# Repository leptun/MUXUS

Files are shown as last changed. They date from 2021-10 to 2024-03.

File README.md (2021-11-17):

# MUXUS
This repository contains the MUXUS project, a USB 2.0 switch with 4 inputs (3xB + 1C_PD) and 4 outputs (3xA + STM32)





The project is split into multiple logical parts, all interconected on a PCB.
1. Upstream USB ports
2. USB mux
3. USB hub
4. Downstream USB ports
5. STM32 microcontroller
6. USB PD sink
7. STM32 programming
8. 3.3V rail Buck converter

## 1. Upstream USB ports
There are 4 upstream capable USB ports (UFP1-UFP4): 3x USB-B and 1xUSB-C

The USB-B ports (UFP2-4) are protected by `USBLC6-2SC6` ICs (VBUS, D+/-).

The USB-C port (UFP1) is protected by a `USBLC6-4SC6` IC (VBUS, D+/-, CC1/2).

## 2. USB mux
All Upstream facing ports (UFP) are connected to the USB mux IC (`TS3USBCA420RSVR`).
The mux output is connected to an internal usb bus called IFP (inner facing port).
Even though this IC is designed to multiplex SBU pins on USB-C ports, its bandwidth is high enough for USB 2.0 signals.
This IC is connected to the MCU via a 400KHz I2C bus. All control is done via I2C.

## 3. USB hub
The IFP bus is split into multiple downstream ports (DFP1-DFP4) using a USB 2.0 HS hub (`USB2504A-JT`).
The hub has an I2C interface as well and it is connected to the MCU via the same 400KHz I2C bus.
Most of the control is done via the I2C bus, but there are also a few extra pins required:
- HUB_RESET. It is an active low signal with an external pull-up resistor. It is needed because the I2C bus gets disabled by the hub when the Attach command is executed by the hub.
- IFP_VBUS. The MCU emulates the VBUS connection of the upstream ports since the MUX IC doesn't do that on its own.

Each DFP has a pair of status LEDs (green and amber):
- The green LED indicates if the device is connected and powered. It turns off when the device is suspended or when it is disconnected.
- The amber LED indicates a fault in the port. This seems to only happen when the VBUS is shorted to GND.

## 4. Downstream USB ports
There are 4 downstream capable ports (DFP1-4), however only 3 have connectors (DFP2-4).

DFP1 is connected directly to the mcu and, as a result, no power circuitry is required for this one.

DFP2-4 are usb-A ports. Each port is protected by `USBLC6-2SC6` ICs (VBUS, D+/-) and VBUS is switched using `AP2151W` ICs.

## 5. STM32 microcontroller
The MCU is a `STM32G441KBU6`.
There are a few reasons why this mcu was chosen, but the main restriction that made me choose this was the IC shortage.

The requirements for the mcu were as follows:
- Enough pins for controlling the board. A QFN32 IC was barely enough for this task. A 48 pin IC would have been much easier to use.
- 4 ADC inputs
- An I2C bus
- USB C PD capabilities
- Some kind of debug interface

Even though these requirements could have been fulfilled by much simpler MCUs, I chose this one as I wanted to learn how to use this MCU family.

## 6. USB PD sink
I wanted this hub to be fully featured, so I made sure that all downstream ports are capable of delivering the full USB 2.0 power specification.
As a result, 1.5A + whatever else consumes power on the board is required. The only method I could achieve this is by either using an external 5V power supply, or by using a USBC-PD capable charger. I chose the latter.
With USBC-PD, the board can communicate with the charger directly and request up to 3A at 5V. I configured it to only request 2A.
The UCPD stack provided by ST is surprisingly heavy, eating up ~70KB of flash. Luckily, it leaves enough flash for the rest of the code.

# 7. STM32 programming
The MCU can be programmed in multiple ways:
- The STDC14 connector is the main method I used. It has a SWD interface, SWO trace support and a UART interface to the programmer, making development extremely easy, especially for the STM32CubeMonitor-UCPD tool. Even though the connector is a bit more expensive than I'd like, it is a single connector debug interface that has everything I'd ever need and it is compatible with the STLINK-V3 programmmer. The connector Part number is `FTSH-107-01-L-DV-K-A`
- A pair of 2.54mm pin headers. The same signals are exposed just like in the STDC14 connector, but in a less pleasant pinout.
- USB DFU firmware upload. If the CYCLE/BOOT0 button is held pressed while the reset button is released, the board enters the system memory boot option, through which code can be uploaded. Due to the way the hub is controlled, resetting the mcu will keep the last mux connection active, so code can be flashed through the mux and hub. There is a small design issue however (more on that in the Known issues section).

# 8. 3.3V rail Buck converter
This buck converter (`AOZ1212AI`) powers all the 3.3V ICs.
It is waaaaay overkill for this project, but I already had the ICs and wanted to implement them.
A small LDO would have been much better suited and it might even have been more stable.

# Known issues
- rev1
  - The ICs are painful to solder. I shouldn't have chosen QFN packages. Lesson learned.
  - The clock circuitry for the hub is wrong. 32pF capacitors should have been used and there should also be a 1M resistor between the crystal leads.
  - The USB signal routing is *horrible*. I'm surprised it works at all. I should improve that aspect if I ever make another revision (:doubt:).
  - There is a pinout conflict between the UCPD dead battery signals and the system memory DFU bootloader. When entering the bootloader, the DBCC1 gets assigned as USART1_TX, disabling the dead battery signal. As a result, power gets cut. This issue can be avoided if the usb C cable is connected with one of the ends reversed, so it works only 50% of the time. There are two solutions for a future revision of the board: I could use a protection IC with integrated DB signals such as the one used in X-NUCLEO-USBPDM1, or I could just use an MCU which doesn't have this pinout conflict (such as STM32G0B1KET6N or similar).
  - The component placement could be better and the board could be smaller.

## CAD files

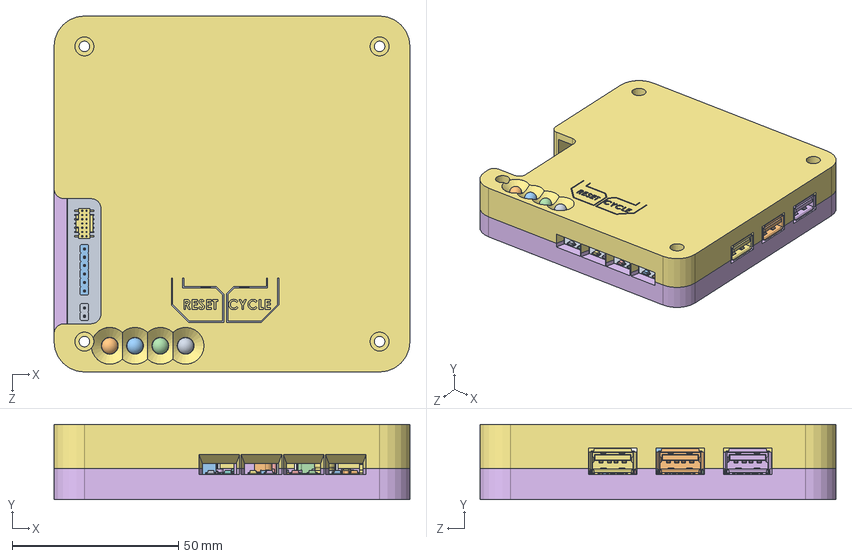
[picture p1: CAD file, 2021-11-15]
Plastic case/MUXUS-full.SLDASM
107.2 x 22.6 x 107.2 mm
Pcb_95df^Board_Geoms_95df_MUXUS
Chamfer^L1_ASSEMBLY_000061512f53_Top_95df_Step_Models_95df_MUXUS
FilletPin1^L1_ASSEMBLY_000061512f53_Top_95df_Step_Models_95df_MUXUS
FilletPin2^L1_ASSEMBLY_000061512f53_Top_95df_Step_Models_95df_MUXUS
FRAME-RSV0016A^FRAME-RSV0016A016_U6_RSV0016A_ASM_0000615132be_Top_95df_Step_Models_95df_MUXUS
FRAME-RSV0016A001^FRAME-RSV0016A016_U6_RSV0016A_ASM_0000615132be_Top_95df_Step_Models_95df_MUXUS
FRAME-RSV0016A002^FRAME-RSV0016A016_U6_RSV0016A_ASM_0000615132be_Top_95df_Step_Models_95df_MUXUS
FRAME-RSV0016A003^FRAME-RSV0016A016_U6_RSV0016A_ASM_0000615132be_Top_95df_Step_Models_95df_MUXUS
FRAME-RSV0016A004^FRAME-RSV0016A016_U6_RSV0016A_ASM_0000615132be_Top_95df_Step_Models_95df_MUXUS
FRAME-RSV0016A005^FRAME-RSV0016A016_U6_RSV0016A_ASM_0000615132be_Top_95df_Step_Models_95df_MUXUS
FRAME-RSV0016A006^FRAME-RSV0016A016_U6_RSV0016A_ASM_0000615132be_Top_95df_Step_Models_95df_MUXUS
FRAME-RSV0016A007^FRAME-RSV0016A016_U6_RSV0016A_ASM_0000615132be_Top_95df_Step_Models_95df_MUXUS
FRAME-RSV0016A008^FRAME-RSV0016A016_U6_RSV0016A_ASM_0000615132be_Top_95df_Step_Models_95df_MUXUS
FRAME-RSV0016A009^FRAME-RSV0016A016_U6_RSV0016A_ASM_0000615132be_Top_95df_Step_Models_95df_MUXUS
FRAME-RSV0016A010^FRAME-RSV0016A016_U6_RSV0016A_ASM_0000615132be_Top_95df_Step_Models_95df_MUXUS
FRAME-RSV0016A011^FRAME-RSV0016A016_U6_RSV0016A_ASM_0000615132be_Top_95df_Step_Models_95df_MUXUS
FRAME-RSV0016A012^FRAME-RSV0016A016_U6_RSV0016A_ASM_0000615132be_Top_95df_Step_Models_95df_MUXUS
FRAME-RSV0016A013^FRAME-RSV0016A016_U6_RSV0016A_ASM_0000615132be_Top_95df_Step_Models_95df_MUXUS
FRAME-RSV0016A014^FRAME-RSV0016A016_U6_RSV0016A_ASM_0000615132be_Top_95df_Step_Models_95df_MUXUS
FRAME-RSV0016A015^FRAME-RSV0016A016_U6_RSV0016A_ASM_0000615132be_Top_95df_Step_Models_95df_MUXUS
BODY-SON1^U6_RSV0016A_ASM_0000615132be_Top_95df_Step_Models_95df_MUXUS
Body^U7_ASSEMBLY_00006158deb1_Top_95df_Step_Models_95df_MUXUS
ThermalPin^U7_ASSEMBLY_00006158deb1_Top_95df_Step_Models_95df_MUXUS
PinsArrayLR^U7_ASSEMBLY_00006158deb1_Top_95df_Step_Models_95df_MUXUS
PinsArrayTB^U7_ASSEMBLY_00006158deb1_Top_95df_Step_Models_95df_MUXUS
C1_C_0805_2012Metric_000061512a82^Top_95df_Step_Models_95df_MUXUS
C2_C_0805_2012Metric_000061512a93^Top_95df_Step_Models_95df_MUXUS
C3_C_0805_2012Metric_000061512aa4^Top_95df_Step_Models_95df_MUXUS
C7_C_1206_3216Metric_000061512ab5^Top_95df_Step_Models_95df_MUXUS
C5_C_1206_3216Metric_000061512ac6^Top_95df_Step_Models_95df_MUXUS
C4_C_1206_3216Metric_000061512ad7^Top_95df_Step_Models_95df_MUXUS
C6_C_1206_3216Metric_000061512ae8^Top_95df_Step_Models_95df_MUXUS
C9_C_0805_2012Metric_000061512b0a^Top_95df_Step_Models_95df_MUXUS
C10_C_0805_2012Metric_000061512b1b^Top_95df_Step_Models_95df_MUXUS
C11_C_0805_2012Metric_000061512b2c^Top_95df_Step_Models_95df_MUXUS
C12_C_0805_2012Metric_000061512b3d^Top_95df_Step_Models_95df_MUXUS
C13_C_0805_2012Metric_000061512b4e^Top_95df_Step_Models_95df_MUXUS
C14_C_0805_2012Metric_000061512b5f^Top_95df_Step_Models_95df_MUXUS
C15_C_Radial_D63mm_H110mm_P250mm_000061512b69^Top_95df_Step_Models_95df_MUXUS
C17_C_0805_2012Metric_000061512b8b^Top_95df_Step_Models_95df_MUXUS
C18_C_0805_2012Metric_000061512b9c^Top_95df_Step_Models_95df_MUXUS
C19_C_0805_2012Metric_000061512bad^Top_95df_Step_Models_95df_MUXUS
C20_C_0805_2012Metric_000061512bbe^Top_95df_Step_Models_95df_MUXUS
C23_C_0805_2012Metric_000061512bf1^Top_95df_Step_Models_95df_MUXUS
C24_C_0805_2012Metric_000061512c02^Top_95df_Step_Models_95df_MUXUS
C26_C_0805_2012Metric_000061512c24^Top_95df_Step_Models_95df_MUXUS
C27_C_0805_2012Metric_000061512c35^Top_95df_Step_Models_95df_MUXUS
C29_C_0805_2012Metric_000061512c50^Top_95df_Step_Models_95df_MUXUS
C31_C_0805_2012Metric_000061512c72^Top_95df_Step_Models_95df_MUXUS
C32_C_0805_2012Metric_000061512c83^Top_95df_Step_Models_95df_MUXUS
C33_C_0805_2012Metric_000061512c94^Top_95df_Step_Models_95df_MUXUS
C34_C_0805_2012Metric_000061512ca5^Top_95df_Step_Models_95df_MUXUS
C35_C_0805_2012Metric_000061512cb6^Top_95df_Step_Models_95df_MUXUS
C36_C_0805_2012Metric_000061512cc7^Top_95df_Step_Models_95df_MUXUS
C38_C_0805_2012Metric_000061512ce2^Top_95df_Step_Models_95df_MUXUS
C39_C_1210_3225Metric_000061512cf3^Top_95df_Step_Models_95df_MUXUS
C40_C_0805_2012Metric_000061512d04^Top_95df_Step_Models_95df_MUXUS
D1_LED_1206_3216Metric_000061512d17^Top_95df_Step_Models_95df_MUXUS
D2_LED_1206_3216Metric_000061512d2a^Top_95df_Step_Models_95df_MUXUS
D3_LED_1206_3216Metric_000061512d3d^Top_95df_Step_Models_95df_MUXUS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

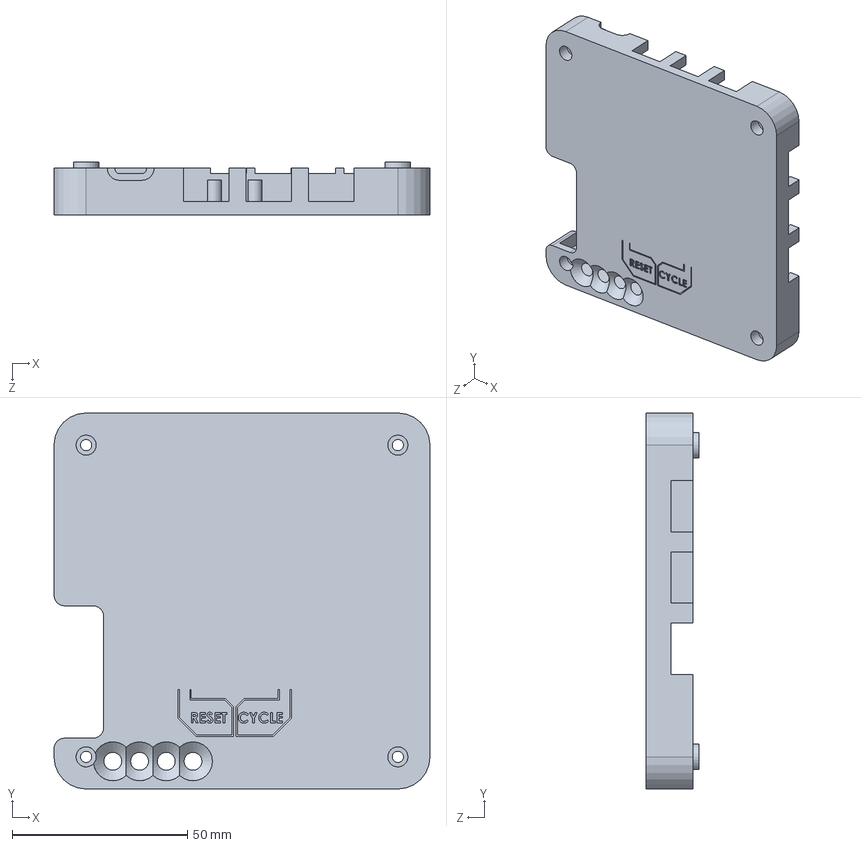
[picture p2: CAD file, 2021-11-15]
Plastic case/MUXUS-top.SLDPRT
107.2 x 107.2 x 15.0 mm

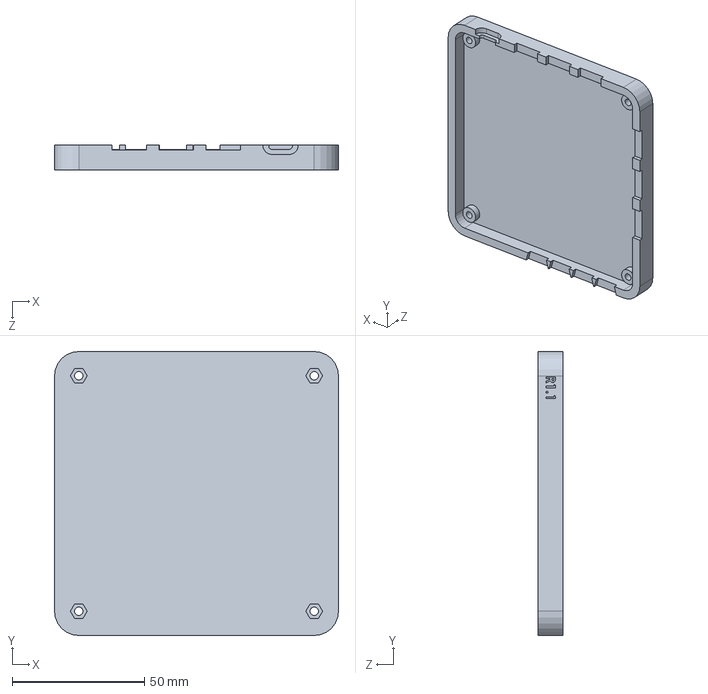
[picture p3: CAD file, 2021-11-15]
Plastic case/MUXUS-base.SLDPRT
107.2 x 107.2 x 9.28 mm

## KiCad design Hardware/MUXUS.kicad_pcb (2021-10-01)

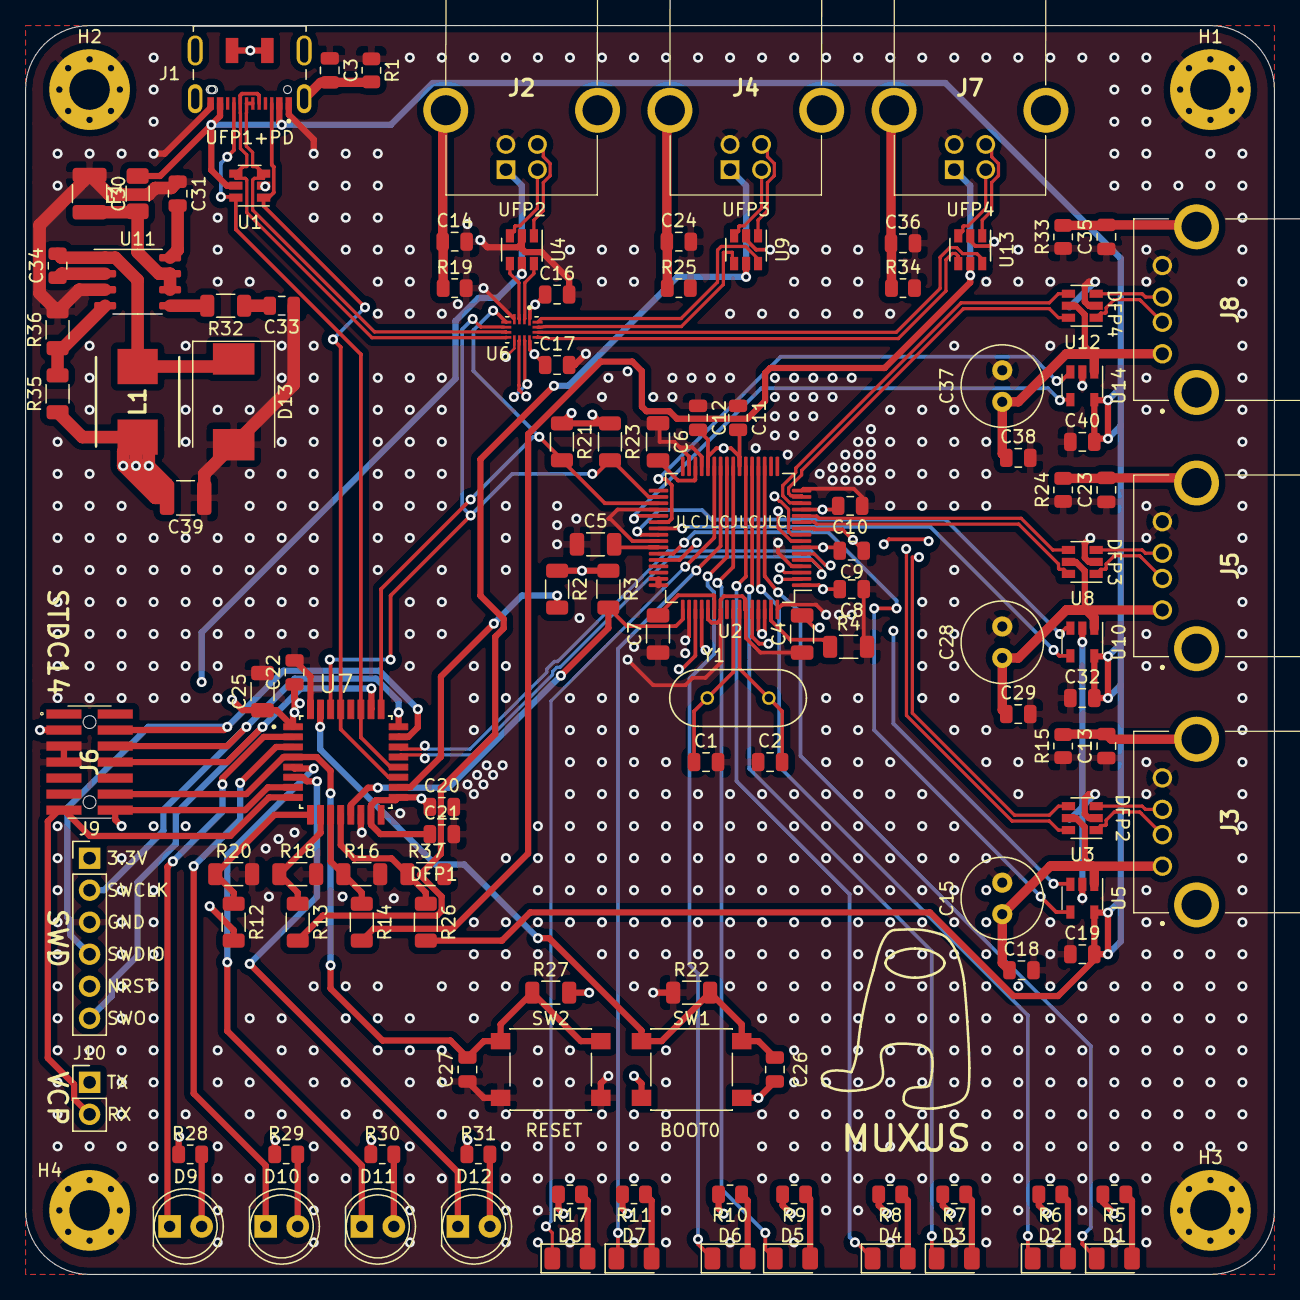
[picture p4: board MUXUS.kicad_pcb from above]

Board: 4 copper layers, 99.1 x 99.1 mm, 124 parts (0 on the bottom side), 107 nets.

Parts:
C1, C2: 15pF; C_0805_2012Metric
C3, C8, C9, C10, C11, C12, C13, C14, C17, C18, C19, C20, C21, C22, C23, C24, C26, C27, C29, C32, C34, C35, C36, C38, C40: 100nF; C_0805_2012Metric
C4, C5, C6, C7, C25: 4.7uF; C_1206_3216Metric
C15, C28, C37: 120uF; C_Radial_D6.3mm_H11.0mm_P2.50mm
C16, C31: 1uF; C_0805_2012Metric
C30, C39: 22uF; C_1210_3225Metric
C33: 100pF; C_0805_2012Metric
D1, D3, D5, D7: AMBER; LED_1206_3216Metric
D2, D4, D6, D8: GREEN; LED_1206_3216Metric
D9, D10, D11, D12: LED; LED_D5.0mm
D13: B540C-13-F; D_SMC
F1: 500mA; Fuse_1206_3216Metric
H1, H2, H3, H4: MountingHole_Pad; MountingHole_3.2mm_M3_Pad_Via
J1: USB_C_Receptacle_USB2.0; DX07S016JA1R1500
J2, J4, J7: USB_B; 67068-9000
J3, J5, J8: USB_A; 67643-0910
J6: STDC14; FTSH-107-01-L-DV-K-A
J9: SWD; PinHeader_1x06_P2.54mm_Vertical
J10: VCP; PinHeader_1x02_P2.54mm_Vertical
L1: SRP6530A-6R8M
R1, R15, R19, R24, R25, R33, R34: 330R; R_0805_2012Metric
R2, R16, R18, R20, R21, R23, R37: 1K; R_1206_3216Metric
R3, R12, R13, R14, R22, R26, R27, R36: 10K; R_1206_3216Metric
R4: 12K; R_1206_3216Metric
R5, R6, R7, R8, R9, R10, R11, R17, R28, R29, R30, R31: 100R; R_0805_2012Metric
R32: 15K; R_1206_3216Metric
R35: 31.6K; R_1206_3216Metric
SW1: USER; SW_Push_1P1T_NO_6x6mm_H9.5mm
SW2: RESET; SW_Push_1P1T_NO_6x6mm_H9.5mm
SYM1: AMOGUS; SUS
U1: USBLC6-4SC6; SOT-23-6
U2: USB2504A-JT; LQFP-64_10x10mm_P0.5mm
U3, U4, U8, U9, U12, U13: USBLC6-2SC6; SOT-23-6
U5, U10, U14: AP2151W; SOT-23-5
U6: TS3USBCA420RSVR
U7: STM32G431K8T6
U11: AOZ1212AI; SO-8_3.9x4.9mm_P1.27mm
Y1: ATS240C

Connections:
+3V3: C8.2, C9.2, C10.2, C11.2, C12.2, C16.1, C17.1, C20.1, C21.1, C22.1, C25.1, C26.1, C39.2, J6.3, J9.1, L1.2, R2.1, R3.1, R5.2, R6.2, R7.2, R8.2, R9.2, R10.2, R11.2, R17.2, R21.1, R23.1, R27.2, R28.1, R29.1, R30.1, R31.1, R35.1, SW1.2, U2.1, U2.7, U2.13, U2.23, U2.28, U2.51, U2.61, U2.62, U6.1, U6.12, U7.1, U7.15, U7.17
BOOT0: C26.2, R22.2, SW1.1, U7.31
CC1: J1.A5, U1.1, U7.19, U7.29
CC2: J1.B5, U1.6, U7.20, U7.27
DFP1_D+: U2.6, U7.22
DFP1_D-: U2.5, U7.21
DFP2_CONN_D+: J3.3, U3.3
DFP2_CONN_D-: J3.2, U3.1
DFP2_D+: U2.8, U3.4
DFP2_D-: U2.9, U3.6
DFP2_EN: U2.43, U5.4
DFP2_OCSn: U2.44, U5.3
DFP3_CONN_D+: J5.3, U8.3
DFP3_CONN_D-: J5.2, U8.1
DFP3_D+: U2.12, U8.4
DFP3_D-: U2.11, U8.6
DFP3_EN: U2.39, U10.4
DFP3_OCSn: U2.40, U10.3
DFP4_CONN_D+: J8.3, U12.3
DFP4_CONN_D-: J8.2, U12.1
DFP4_D+: U2.14, U12.4
DFP4_D-: U2.15, U12.6
DFP4_EN: U2.37, U14.4
DFP4_OCSn: U2.38, U14.3
GND: C1.2, C2.1, C3.1, C4.1, C5.1, C6.1, C7.1, C8.1, C9.1, C10.1, C11.1, C12.1, C13.1, C14.2, C15.2, C16.2, C17.2, C18.2, C19.1, C20.2, C21.2, C22.2, C23.1, C24.2, C25.2, C27.1, C28.2, C29.2, C30.1, C31.1, C32.1, C33.1, C35.1, C36.2, C37.2, C38.2, C39.1, C40.1, D13.2, H1.1, H2.1, H3.1, H4.1, J1.A1, J1.A12, J1.B1, J1.B12, J2.4, J3.4, J4.4, J5.4, J6.5, J6.7, J7.4, J8.4, J9.3, R1.1, R4.2, R15.1, R16.2, R18.2, R19.2, R20.2, R22.1, R24.1, R25.2, R33.1, R34.2, R36.2, R37.2, SW2.2, U1.2, U2.4, U2.10, U2.16, U2.29, U2.31, U2.36, U2.41, U2.47, U2.48, U2.50, U2.53, U2.55, U2.59, U2.64, U3.2, U4.2, U5.2, U6.4, U6.9, U7.14, U7.16, U7.32, U8.2, U9.2, U10.2, U11.3, U12.2, U13.2, U14.2
HUB_RESET: R3.2, U2.49, U7.13
I2C1_SCL: R21.2, U2.35, U6.5, U7.25
I2C1_SDA: R23.2, U2.34, U6.6, U7.30
IFP_D+: U2.2, U6.11
IFP_D-: U2.3, U6.10
IFP_VBUS: R2.2, U2.52, U7.18
LPUART1_RX: J6.13, J10.2, U7.8
LPUART1_TX: J6.14, J10.1, U7.7
NRST: C27.2, J6.12, J9.5, R27.1, SW2.1, U7.4
unnamed: C1.1, U2.57, Y1.1
unnamed: C2.2, U2.58, Y1.2
unnamed: C3.2, J1.S1, R1.2
unnamed: C4.2, U2.60
unnamed: C5.2, U2.42
unnamed: C6.2, U2.30
unnamed: C7.2, U2.54
unnamed: C13.2, J3.5, R15.2
unnamed: C14.1, J2.5, R19.1
unnamed: C15.1, C18.1, J3.1, U3.5, U5.1
unnamed: C23.2, J5.5, R24.2
unnamed: C24.1, J4.5, R25.1
unnamed: C28.1, C29.1, J5.1, U8.5, U10.1
unnamed: C30.2, F1.1, U11.6, U11.7
unnamed: C31.2, U11.8
unnamed: C33.2, R32.1
unnamed: C34.1, U11.2
unnamed: C34.2, D13.1, L1.1, U11.1
unnamed: C35.2, J8.5, R33.2
unnamed: C36.1, J7.5, R34.1
unnamed: C37.1, C38.1, J8.1, U12.5, U14.1
unnamed: D1.1, U2.19
unnamed: D1.2, R5.1
unnamed: D2.1, U2.20
unnamed: D2.2, R6.1
unnamed: D3.1, U2.21
unnamed: D3.2, R7.1
unnamed: D4.1, U2.22
unnamed: D4.2, R8.1
unnamed: D5.1, U2.24
unnamed: D5.2, R9.1
unnamed: D6.1, U2.25
unnamed: D6.2, R10.1
unnamed: D7.1, U2.26
unnamed: D7.2, R11.1
unnamed: D8.1, U2.27
unnamed: D8.2, R17.1
unnamed: D9.2, R28.2
unnamed: D10.2, R29.2
unnamed: D11.2, R30.2
unnamed: D12.2, R31.2
unnamed: R4.1, U2.63
unnamed: R12.1, R20.1, U7.9
unnamed: R13.1, R18.1, U7.10
unnamed: R14.1, R16.1, U7.11
unnamed: R26.1, R37.1, U7.12
unnamed: R32.2, U11.5
unnamed: R35.2, R36.1, U11.4
SWCLK: J6.6, J9.2, U7.24
SWDIO: J6.4, J9.4, U7.23
SWO: J6.8, J9.6, U7.26
UFP1_D+: J1.A6, J1.B6, U1.3, U6.7
UFP1_D-: J1.A7, J1.B7, U1.4, U6.8
UFP1_VBUS: C19.2, C32.2, C40.2, F1.2, J1.A4, J1.A9, J1.B4, J1.B9, R26.2, U1.5, U5.5, U10.5, U14.5
UFP2_CONN_D+: J2.3, U4.1
UFP2_CONN_D-: J2.2, U4.3
UFP2_D+: U4.6, U6.2
UFP2_D-: U4.4, U6.3
UFP2_VBUS: J2.1, R12.2, U4.5
UFP3_CONN_D+: J4.3, U9.1
UFP3_CONN_D-: J4.2, U9.3
UFP3_D+: U6.16, U9.6
UFP3_D-: U6.15, U9.4
UFP3_VBUS: J4.1, R13.2, U9.5
UFP4_CONN_D+: J7.3, U13.1
UFP4_CONN_D-: J7.2, U13.3
UFP4_D+: U6.14, U13.6
UFP4_D-: U6.13, U13.4
UFP4_VBUS: J7.1, R14.2, U13.5
UI_LED1: D9.1, U7.2
UI_LED2: D10.1, U7.3
UI_LED3: D11.1, U7.5
UI_LED4: D12.1, U7.6

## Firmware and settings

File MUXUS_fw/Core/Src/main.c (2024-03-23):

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
/* Includes ------------------------------------------------------------------*/
#include "main.h"
#include "cmsis_os.h"
#include "usbpd.h"
#include "usb_device.h"

/* USER CODE BEGIN Includes */

#include <bootapp.h>

/* USER CODE END Includes */

ADC_HandleTypeDef hadc1;
ADC_HandleTypeDef hadc2;
DMA_HandleTypeDef hdma_adc1;

I2C_HandleTypeDef hi2c1;
DMA_HandleTypeDef hdma_i2c1_rx;
DMA_HandleTypeDef hdma_i2c1_tx;

/* Definitions for defaultTask */
osThreadId_t defaultTaskHandle;
const osThreadAttr_t defaultTask_attributes = {
  .name = "defaultTask",
  .priority = (osPriority_t) osPriorityNormal,
  .stack_size = 128 * 4
};
/* Definitions for controlTask */
osThreadId_t controlTaskHandle;
const osThreadAttr_t controlTask_attributes = {
  .name = "controlTask",
  .priority = (osPriority_t) osPriorityNormal,
  .stack_size = 256 * 4
};
void SystemClock_Config(void);
static void MX_GPIO_Init(void);
static void MX_DMA_Init(void);
static void MX_ADC1_Init(void);
static void MX_ADC2_Init(void);
static void MX_I2C1_Init(void);
static void MX_LPUART1_UART_Init(void);
static void MX_UCPD1_Init(void);
void StartDefaultTask(void *argument);
extern void controlTask_main(void *argument);

/**
  * @brief  The application entry point.
  * @retval int
  */
int main(void)
{
  /* USER CODE BEGIN 1 */
  bootapp();
  /* USER CODE END 1 */

  /* MCU Configuration--------------------------------------------------------*/

  /* Reset of all peripherals, Initializes the Flash interface and the Systick. */
  HAL_Init();

  /* Configure the system clock */
  SystemClock_Config();

  /* Initialize all configured peripherals */
  MX_GPIO_Init();
  MX_DMA_Init();
  MX_ADC1_Init();
  MX_ADC2_Init();
  MX_I2C1_Init();
  MX_LPUART1_UART_Init();
  MX_UCPD1_Init();
  MX_USB_Device_Init();
  /* Init scheduler */
  osKernelInitialize();
  /* USBPD initialisation ---------------------------------*/
  MX_USBPD_Init();

  /* USER CODE BEGIN RTOS_MUTEX */
  /* add mutexes, ... */
  /* USER CODE END RTOS_MUTEX */

  /* USER CODE BEGIN RTOS_SEMAPHORES */
  /* add semaphores, ... */
  /* USER CODE END RTOS_SEMAPHORES */

  /* USER CODE BEGIN RTOS_TIMERS */
  /* start timers, add new ones, ... */
  /* USER CODE END RTOS_TIMERS */

  /* USER CODE BEGIN RTOS_QUEUES */
  /* add queues, ... */
  /* USER CODE END RTOS_QUEUES */

  /* Create the thread(s) */
  /* creation of defaultTask */
  defaultTaskHandle = osThreadNew(StartDefaultTask, NULL, &defaultTask_attributes);

  /* creation of controlTask */
  controlTaskHandle = osThreadNew(controlTask_main, NULL, &controlTask_attributes);

  /* USER CODE BEGIN RTOS_THREADS */
  /* add threads, ... */
  /* USER CODE END RTOS_THREADS */

  /* USER CODE BEGIN RTOS_EVENTS */
  /* add events, ... */
  /* USER CODE END RTOS_EVENTS */

  /* Start scheduler */
  osKernelStart();

  /* We should never get here as control is now taken by the scheduler */
  /* Infinite loop */
  /* USER CODE BEGIN WHILE */
  while (1)
  {
    /* USER CODE END WHILE */

    /* USER CODE BEGIN 3 */
  }
  /* USER CODE END 3 */
}

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
/* USER CODE BEGIN Header_StartDefaultTask */
/**
  * @brief  Function implementing the defaultTask thread.
  * @param  argument: Not used
  * @retval None
  */
/* USER CODE END Header_StartDefaultTask */
void StartDefaultTask(void *argument)
{
  /* USER CODE BEGIN 5 */
  /* Infinite loop */
	for (;;)
		osDelay(1);
  /* USER CODE END 5 */
}

/**
  * @brief  Period elapsed callback in non blocking mode
  * @note   This function is called  when TIM6 interrupt took place, inside
  * HAL_TIM_IRQHandler(). It makes a direct call to HAL_IncTick() to increment
  * a global variable "uwTick" used as application time base.
  * @param  htim : TIM handle
  * @retval None
  */
void HAL_TIM_PeriodElapsedCallback(TIM_HandleTypeDef *htim)
{
  if (htim->Instance == TIM6) {
    HAL_IncTick();
  }
  /* USER CODE BEGIN Callback 1 */
#ifdef _GUI_INTERFACE
  if (htim->Instance == TIM6) {
	  GUI_TimerCounter();
  }
#endif
  /* USER CODE END Callback 1 */
}

/**
  * @brief  This function is executed in case of error occurrence.
  * @retval None
  */
void Error_Handler(void)
{
  /* USER CODE BEGIN Error_Handler_Debug */
  /* User can add his own implementation to report the HAL error return state */
  __disable_irq();
  while (1)
  {
  }
  /* USER CODE END Error_Handler_Debug */
}

#ifdef  USE_FULL_ASSERT
/**
  * @brief  Reports the name of the source file and the source line number
  *         where the assert_param error has occurred.
  * @param  file: pointer to the source file name
  * @param  line: assert_param error line source number
  * @retval None
  */
void assert_failed(uint8_t *file, uint32_t line)
{
  /* USER CODE BEGIN 6 */
  /* User can add his own implementation to report the file name and line number,
     ex: printf("Wrong parameters value: file %s on line %d\r\n", file, line) */
  /* USER CODE END 6 */
}
#endif /* USE_FULL_ASSERT */

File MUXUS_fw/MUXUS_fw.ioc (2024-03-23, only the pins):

Mcu.UserName=STM32G441KBUx
PA0.GPIO_Label=VOLT3
PA0.Signal=ADC1_IN1
PA1.GPIO_Label=VOLT4
PA1.Signal=ADC1_IN2
PA10.Signal=UCPD1_DBCC2
PA11.Signal=USB_DM
PA12.Signal=USB_DP
PA13.Signal=SYS_JTMS-SWDIO
PA14.Signal=SYS_JTCK-SWCLK
PA15.Signal=I2C1_SCL
PA2.Signal=LPUART1_TX
PA3.Signal=LPUART1_RX
PA4.GPIO_Label=LED1
PA4.Signal=GPIO_Output
PA5.GPIO_Label=LED2
PA5.Signal=GPIO_Output
PA6.GPIO_Label=LED3
PA6.Signal=GPIO_Output
PA7.GPIO_Label=LED4
PA7.Signal=GPIO_Output
PA8.GPIO_Label=IFP_VBUS
PA8.Signal=GPIO_Output
PA9.Signal=UCPD1_DBCC1
PB0.GPIO_Label=HUB_RESET
PB0.Signal=GPIO_Output
PB3.Signal=SYS_JTDO-SWO
PB4.Signal=UCPD1_CC2
PB5.Signal=I2C1_SMBA
PB6.Signal=UCPD1_CC1
PB7.Signal=I2C1_SDA
PB8-BOOT0.GPIO_Label=BOOT0
PB8-BOOT0.Signal=GPIO_Input
PF0-OSC_IN.GPIO_Label=VOLT2
PF0-OSC_IN.Signal=ADC1_IN10
PF1-OSC_OUT.GPIO_Label=VOLT1
PF1-OSC_OUT.Signal=ADC2_IN10
PG10-NRST.GPIO_Label=NRST
PG10-NRST.Signal=GPIO_Input

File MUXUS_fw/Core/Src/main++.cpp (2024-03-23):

#include "pins.hpp"

#include "main.h"
#include "cmsis_os.h"
#include "bootapp.h"

#include <usb_device.h>

////std libs
//#include <stdio.h>
//#include <algorithm>

//libs
#include "USB2504A/USB2504A.hpp"
#include "TS3USBCA4/TS3USBCA4.hpp"

I2C_Wrapper i2c_bus(&hi2c1, "i2c_bus");
USB2504A hub(0x58, pins::HUB.RST, pins::HUB.IFP_VBUS, &i2c_bus);
TS3USBCA4 mux(0xBA, &i2c_bus);

constexpr TS3USBCA4::Channels upstreams[] {
	TS3USBCA4::Channels::DISABLED,
	TS3USBCA4::Channels::LnB,
	TS3USBCA4::Channels::MICGND,
	TS3USBCA4::Channels::LnA,
	TS3USBCA4::Channels::LnC,
};

uint8_t activeUpstream;
constexpr uint8_t defaultUpstream = 2;

constexpr USB2504A::Config hubConfig = {
	0x0424,
	0x2504,
	0x10A1,
	0xDB,
	0x18,
	0x02,
	0x00,
	0x00,
	0x00,
	0x64,
	0x00,
	0x64,
	0x32,
};

void switchToUpstream(uint8_t port) {
	activeUpstream = port;
	hub.reset();
	mux.setChannel(upstreams[activeUpstream], false);
	hub.writeConfig(hubConfig);
	hub.attach();

	for (uint8_t i = 0; i < (sizeof(pins::LEDs) / sizeof(pins::LEDs[0])); i++) {
		HAL_GPIO_WritePin(pins::LEDs[i].port, pins::LEDs[i].pin, ((i + 1) == activeUpstream) ? GPIO_PIN_RESET : GPIO_PIN_SET);
	}
}


uint32_t lastMSC_Pulse = 0;

void notify_check_for_ready(void) {
	lastMSC_Pulse = osKernelGetTickCount();
}

extern "C" void controlTask_main(void *argument) {
	osDelay(500);
	hub.init();
	mux.init();

	switchToUpstream(defaultUpstream);

	for(;;osDelay(1)) {
		if (HAL_GPIO_ReadPin(pins::USER.port, pins::USER.pin)) {
			uint32_t startTime = osKernelGetTickCount();
			osDelay(10); //debounce
			while (HAL_GPIO_ReadPin(pins::USER.port, pins::USER.pin))
				osDelay(1);
			uint32_t deltaTime = osKernelGetTickCount() - startTime;

			if (deltaTime < 5000) {
				activeUpstream++;
				if (activeUpstream >= (sizeof(upstreams) / sizeof(upstreams[0])))
					activeUpstream = 1;
				switchToUpstream(activeUpstream);
			}
			else {
				boot_app_magic = BOOT_APP_MAGIC;
				boot_app_flags = BOOT_APP_JMP_TO_SYSTEM_MEMORY;
				HAL_NVIC_SystemReset();
			}
		}

		if (osKernelGetTickCount() - lastMSC_Pulse > 10000) {
			MX_USB_Device_DeInit();
			osDelay(500);
			MX_USB_Device_Init();
			lastMSC_Pulse = osKernelGetTickCount();
		}
	}
}

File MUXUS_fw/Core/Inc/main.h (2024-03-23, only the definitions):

#define VOLT2_Pin GPIO_PIN_0
#define VOLT2_GPIO_Port GPIOF
#define VOLT1_Pin GPIO_PIN_1
#define VOLT1_GPIO_Port GPIOF
#define NRST_Pin GPIO_PIN_10
#define NRST_GPIO_Port GPIOG
#define VOLT3_Pin GPIO_PIN_0
#define VOLT3_GPIO_Port GPIOA
#define VOLT4_Pin GPIO_PIN_1
#define VOLT4_GPIO_Port GPIOA
#define LED1_Pin GPIO_PIN_4
#define LED1_GPIO_Port GPIOA
#define LED2_Pin GPIO_PIN_5
#define LED2_GPIO_Port GPIOA
#define LED3_Pin GPIO_PIN_6
#define LED3_GPIO_Port GPIOA
#define LED4_Pin GPIO_PIN_7
#define LED4_GPIO_Port GPIOA
#define HUB_RESET_Pin GPIO_PIN_0
#define HUB_RESET_GPIO_Port GPIOB
#define IFP_VBUS_Pin GPIO_PIN_8
#define IFP_VBUS_GPIO_Port GPIOA
#define BOOT0_Pin GPIO_PIN_8
#define BOOT0_GPIO_Port GPIOB

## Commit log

2021-09-12 Initial project
    [MUXUS.kicad_pcb, MUXUS.sch]
2021-09-12 First libs and project reorganization into HW and SW
    [MUXUS.kicad_pcb, MUXUS.sch]
2021-09-24 Checkpoint
    Supposed finalization of first prototype
    [MUXUS.sch]
2021-09-26 Prototype 1
2021-09-26 Mounting holes
    [MUXUS.sch]
2021-09-26 Basic board layout
    [MUXUS.kicad_pcb, MUXUS.sch]
2021-09-26 LED positioning
    [MUXUS.kicad_pcb]
2021-09-26 More footprint positioning
    [MUXUS.kicad_pcb]
2021-09-27 add older footprint from desktop
    todo: make combined libraries
2021-09-27 AMOGUS and USB C footprint update
    [MUXUS.kicad_pcb, MUXUS.sch]
2021-09-27 Component placement finished
    [MUXUS.kicad_pcb]
2021-09-27 Rounded board edges
    [MUXUS.kicad_pcb]
2021-09-27 Add trace widths
    [MUXUS.kicad_pcb]
2021-09-27 Basic routing
    [MUXUS.kicad_pcb]
2021-09-27 First PCB routing
    [MUXUS.kicad_pcb, MUXUS.sch]
2021-09-28 Add labels on silkscreen
    [MUXUS.kicad_pcb]
2021-09-28 DEBUG connectors and VIAS
    [MUXUS.kicad_pcb, MUXUS.sch]
2021-09-28 Repair via gaps
    [MUXUS.kicad_pcb]
2021-10-01 Measure UFP1_VBUS as well for the UCPD stack
    [MUXUS.kicad_pcb, MUXUS.sch]
2021-10-02 Updated STM32G441KBU6
    [MUXUS.sch]
2021-10-03 Repaired routing and fixed some 3d models
    [ATS240C.STEP, MUXUS.kicad_pcb, MUXUS.sch]
2021-10-03 Include solidworks model as well
    [ATS240C.SLDPRT]
2021-10-03 USB, mux and 3d models update
    [MUXUS.kicad_pcb, MUXUS.sch]
2021-10-03 Update UFP1 routing
    [MUXUS.kicad_pcb, MUXUS.sch]
2021-10-04 Tiny updates and first production test
    [MUXUS-B_Cu.gbl, MUXUS-B_Mask.gbs, MUXUS-B_Paste.gbp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]
2021-10-08 Filled all zones
    [MUXUS.kicad_pcb]
2021-10-08 Test new kicad
    [MUXUS.kicad_sch]
2021-10-08 TS3USBCA420RSVR
    .
    [MUXUS.kicad_sch]
2021-10-09 Remove old stuff and backups
    [MUXUS.kicad_pcb, MUXUS.sch]
2021-10-09 Regenerate output
    [MUXUS-B_Cu.gbl, MUXUS-B_Paste.gbp, MUXUS-B_SilkS.gbo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]
2021-10-09 Revision 1 + update output
    [MUXUS-B_Cu.gbl, MUXUS-B_Mask.gbs, MUXUS-B_Paste.gbp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]
2021-10-18 Fix VCP and SWD silkscreen orientation
2021-10-24 Regenerate project output
    [MUXUS-B_Cu.gbl, MUXUS-B_Mask.gbs, MUXUS-B_Paste.gbp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]
2021-11-15 Plastic case R1.1
    [MUXUS-base.SLDPRT, MUXUS-full.SLDASM, MUXUS-top.SLDPRT]
2021-11-15 Add delay on main task startup. It helps with firmware upload reset cnt
    [main++.cpp]
2021-11-17 Update gitignore
    [MUXUS_fw.cfg]
2024-03-23 Switch to usb msc
2024-03-23 Add bowser bios workaround for getting it unstuck
    [main++.cpp, main.h]

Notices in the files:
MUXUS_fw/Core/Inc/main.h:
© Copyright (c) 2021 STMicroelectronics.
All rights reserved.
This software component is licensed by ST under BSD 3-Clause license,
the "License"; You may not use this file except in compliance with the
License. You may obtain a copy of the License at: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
